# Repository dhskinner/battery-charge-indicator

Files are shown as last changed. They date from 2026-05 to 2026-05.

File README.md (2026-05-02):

# Battery Charge Indicator

Battery Charge Indicator is an ATTiny84-based embedded monitor for lead-acid battery charging systems.

The firmware determines whether charging is active by combining three inputs:

1. Mains AC detection at the charger input (nominal 240V, detected via an isolated/no-contact sensing path).
2. Primary battery DC level above a charging threshold.
3. Secondary battery/house-master channel condition indicating the system state allows charging indication.

When charging is detected, a 12V output runs a repeating PWM fade cycle to drive an external indicator LED. The board also drives onboard status LEDs for quick diagnostics.

## 1) Functionality

### High-level behavior

At runtime, the firmware continuously evaluates three channels:

- **Mains channel** (`channelMains`): checks for a stable AC waveform around 50Hz.
- **Primary channel** (`channelPrimary`): checks DC voltage against a charging threshold.
- **Secondary channel** (`channelSecondary`): checks DC state used as an interlock/condition.

Charging is considered present only when all are true:

- mains AC present,
- primary battery voltage present (above threshold),
- secondary channel **not** present.

This logic is implemented in `IsCharging()` in `src/main.cpp` with a debounce window to avoid false transitions.

### Debounce and signal conditioning

- **Charge-state debounce:** `DEBOUNCE_HYSTERISIS_MS` (default `1000 ms`) requires stable readings before state changes.
- **AC detection debounce:** mains detection validates repeated leading edges in a 50Hz timing window:
	- min interval `15 ms`
	- max interval `25 ms`
	- continuous detection timeout/hysteresis `200 ms`

### PWM output behavior

When charging starts:

- output fade cycle starts (`Fader::StartFade()`),
- brightness ramps up and down using `analogWrite()`,
- step and timing are controlled by:
	- `OUTPUT_PWM_FADE_STEP` (default `4`)
	- `OUTPUT_PWM_FADE_MILLIS` (default `10 ms`)
	- `OUTPUT_PWM_CYCLE_MILLIS` (default `3000 ms` between cycles)

When charging stops:

- fade is stopped gracefully (`Fader::StopFade()`),
- output returns to off state at the end of the current fade cycle.

### Default ATTiny84A channel configuration

Defined in `src/config.h`:

- **Primary sense pin:** `D2`, threshold `13.0V`, scale `21.01V`
- **Secondary sense pin:** `D3`, threshold `10.0V`, scale `21.01V`
- **Mains sense pin:** `D0`, digital threshold `LOW`
- **PWM output pin:** `D8`
- **Onboard LEDs:** primary `D9`, secondary `D10`, mains `D7`

### Startup behavior

On boot (normal mode), the firmware:

1. initializes sensing channels and output,
2. flashes each onboard channel/output LED (`START_FLASHES`, `START_FLASH_MS`),
3. waits `START_DELAY_MS` before entering main loop.

### Optional operating modes

Compile-time options in `src/config.h`:

- `ENABLE_WATCHDOG_TIMER`: enable the watchdog timer for automatic recovery from lockups.
- `ENABLE_WATCHDOG_LOCKUP_TEST`: run a test that watchdog works (not for production code) 
- `ENABLE_CALIBRATION_MODE`: samples ADC channels and blinks out measured values for field calibration.
- `ENABLE_PIN_TEST_MODE`: basic pin/LED test routine (`src/pintest.h`) for validating board mapping and outputs.

## 2) Source Code and Build (PlatformIO)

### Repository layout

- `src/main.cpp`: application setup/loop and charging-state logic.
- `src/channel.h/.cpp`: generic channel abstraction, DC thresholding, AC edge timing.
- `src/fader.h/.cpp`: PWM fade output state machine.
- `src/config.h`: target, pins, thresholds, timing constants, feature flags.
- `src/pintest.h`: pin test helper mode.
- `platformio.ini`: build environment (`attiny84`), upload protocol (`usbasp`), CPU clock, variant.

### Toolchain

- [PlatformIO](https://platformio.org/) with VS Code, or PlatformIO Core CLI.
- AVR target from `platformio.ini`:
	- platform: `atmelavr`
	- board: `attiny84`
	- framework: `arduino`
	- upload protocol: `usbasp`
	- MCU: `attiny84`
	- frequency: `8000000L`
	- variant: `tinyX4_reverse`

### Build and upload using VS Code

1. Open this folder in VS Code.
2. Ensure PlatformIO extension is installed.
3. Open the PlatformIO panel.
4. Under **Project Tasks -> attiny84**:
	 - run **Build** to compile,
	 - run **Upload** to flash via USBasp.

### Build and upload using CLI

From the project root:

```bash
pio run
pio run -t upload
```

### Setting bootloader/fuse for fresh ATTiny84A devices

To burn the bootloader to a fresh Attiny:

1) connect the ICSP header from USBAsp to the target board

```
      ATTiny84A Expander Daughter Board (purple)
      -----------------------------------------
                  -----
      pin 1 MISO |*    | pin 2 5V+
      pin 3 SCK  |     | pin 4 MOSI
      pin 5 RST  |     | pin 6 GND
                  -----
```

2) Setup USBAsp board - refer to here for a guide to USBAsp https://www.freetronics.com.au/pages/usbasp-icsp-programmer-quickstart-guide:
- jumper the "slow clock" header
- select "5V" on the target voltage selection switch
- jumper the 'target power' header

3) Setup some sensible options:
- Board:              Attiny 24/44/84a (no bootloader)
- B.O.D. Level:       Enabled 4.3V (brownout detection) (!! IMPORTANT !!)
- Chip:               Attiny84(a)
- Clock Source:       8MHz (internal)
- Save EEPROM:        EEPROM not retained
- LTO:                Enabled
- millis()/micros():  Enabled
- tinyNeoPixel:       Port A
- Pin mapping:        Clockwise (!! IMPORTANT !!)
- Programmer:         USBAsp (ATTiny Core)

4) Burn bootloader and check all is ok i.e. 2 bytes written

5) On the USBAsp board, remove the "Slow Clock" jumper

6) For a simple proof-of-life test either:
- run a 'Blink' sketch using pin 7,8,9 or 10 (see "pintest.h" for LED pinouts)
- uncomment #define PIN_TEST_MODE below to see all four LED's blinking at the same time
- upload and run this sample:

```code
          int led_pin[4] = {7, 8, 9, 10}, led_index = 0;
          void setup() {
            for (; led_index < 4; led_index++) {
              pinMode(led_pin[led_index], OUTPUT);
              digitalWrite(led_pin[led_index], LOW);
          }}
          void loop() {
            led_index = led_index >= 3 ? 0 : led_index + 1;
            digitalWrite(led_pin[led_index], HIGH); delay(100);
            digitalWrite(led_pin[led_index], LOW); delay(100);
          }
```

7) Upload the production program code as normal using PlatformIO and USBAsp connected via ICSP:
- go to the PlatformIO tab in VSCode and 'Open" this project
- when config is complete, go to the PIO menu bar to the left of the VSCode working area
- the menu for "Project Tasks" should be visible - hit "Upload"

### Fuse bits

`platformio.ini` sets expected signature/fuse values.

Alternatively, the tool AVRDUDESS at (https://github.com/ZakKemble/AVRDUDESS)[https://github.com/ZakKemble/AVRDUDESS] is an easy way to check and set fuse bits.

To read fuse settings run the provided script in Powershell:

```bash
.\tools\read-attiny84a-fuses.ps1 -AvrDude "C:\Program Files (x86)\AVRDUDESS\avrdude.exe" 
```

Or alternatively run: 

```bash
avrdude -c usbasp -p t84 -U efuse:r:-:h -U hfuse:r:-:h -U lfuse:r:-:h
```

Expected values are:

```bash
ATtiny84A fuse report
--------------------
LFUSE: 0xE2
HFUSE: 0xDC
EFUSE: 0xFF

Low fuse (LFUSE)
  CKDIV8     OFF (bit7=1) - Clock divide-by-8 enabled
  CKOUT      OFF (bit6=1) - System clock output on CLKO enabled
  SUT1       ON  (bit5=1) - Start-up time select bit 1
  SUT0       OFF (bit4=0) - Start-up time select bit 0
  CKSEL3     OFF (bit3=0) - Clock source select bit 3
  CKSEL2     OFF (bit2=0) - Clock source select bit 2
  CKSEL1     ON  (bit1=1) - Clock source select bit 1
  CKSEL0     OFF (bit0=0) - Clock source select bit 0
  SUT[1:0]      0b10
  CKSEL[3:0]    0b0010

High fuse (HFUSE)
  RSTDISBL   OFF (bit7=1) - External RESET pin disabled
  DWEN       OFF (bit6=1) - debugWIRE enabled
  SPIEN      ON  (bit5=0) - ISP serial programming enabled
  WDTON      OFF (bit4=1) - Watchdog always on (hardware forced)
  EESAVE     OFF (bit3=1) - EEPROM preserved through chip erase
  BODLEVEL2  ON  (bit2=1) - Brown-out level select bit 2
  BODLEVEL1  OFF (bit1=0) - Brown-out level select bit 1
  BODLEVEL0  OFF (bit0=0) - Brown-out level select bit 0
  BODLEVEL[2:0] 0b100

Extended fuse (EFUSE)
  RES7       ON  (bit7=1) - Reserved (typically left as 1)
  RES6       ON  (bit6=1) - Reserved (typically left as 1)
  RES5       ON  (bit5=1) - Reserved (typically left as 1)
  RES4       ON  (bit4=1) - Reserved (typically left as 1)
  RES3       ON  (bit3=1) - Reserved (typically left as 1)
  RES2       ON  (bit2=1) - Reserved (typically left as 1)
  RES1       ON  (bit1=1) - Reserved (typically left as 1)
  SELFPRGEN  OFF (bit0=1) - Self-programming (SPM) enabled

Note: many AVR fuse features are active-low (bit = 0 means programmed/enabled).
```

Notes: 
1. This firmware is currently configured for `TARGET_PROCESSOR_ATTINY84`
2. Its essential to keep pin mapping/clock settings aligned with your board core configuration when burning fuses. If changing pin mapping, ensure the selected core variant and hardware mapping are consistent before flashing.
3. Many AVR fuse features are active-low (bit = 0 means programmed/enabled).
4. Enabling BOD increases power consumption slightly.
5. Higher BOD thresholds can cause more frequent resets on brief supply dips.
6. If the MCU appears unresponsive after incorrect fuse settings, use HV rescue tooling as referenced in the source comments.

### Calibration

Calibration of the 12V sense lines is performed manually and adjusted in source code. The input voltage range is approximately 0VDC to +20VDC, and ADC response is reasonably linear, as follows:

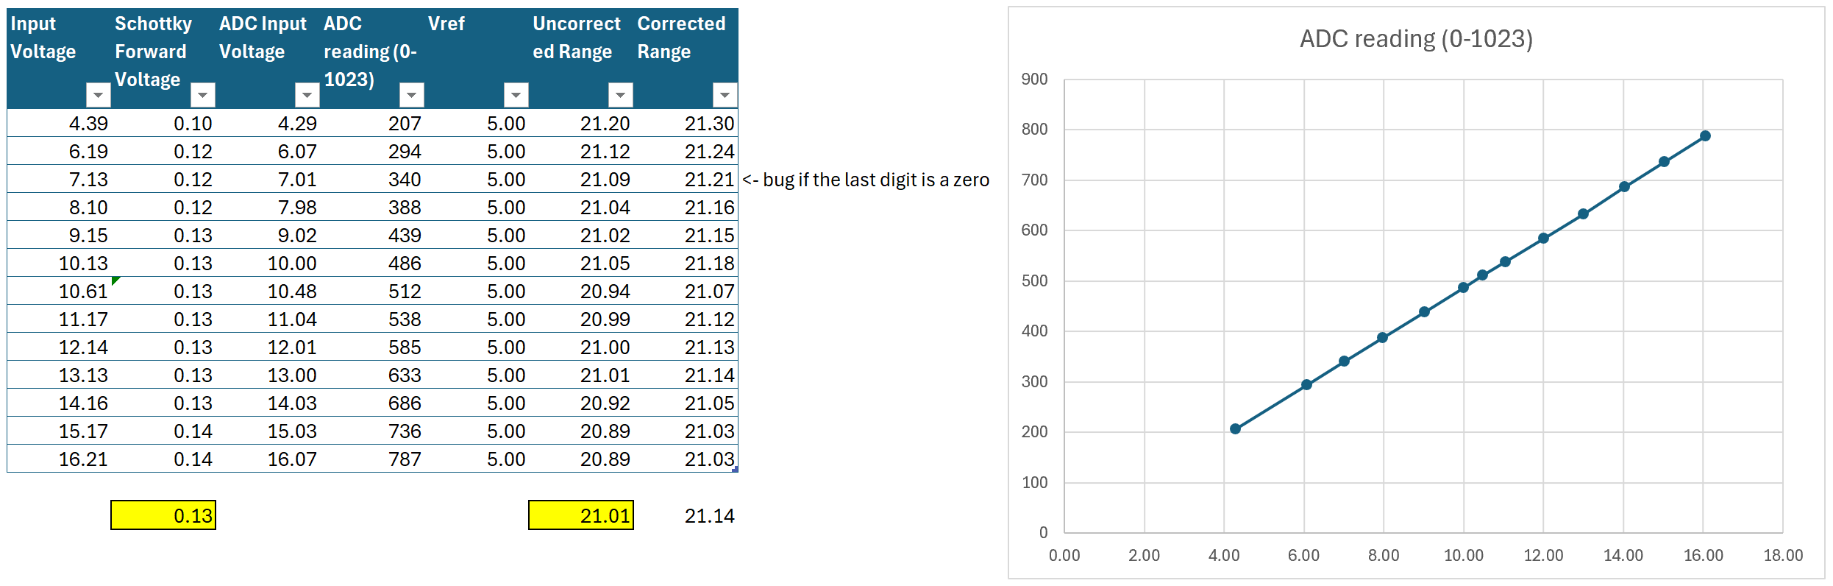
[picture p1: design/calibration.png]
Calibration Reference


- `design/calibration.xlsx`: calibration data workbook.
- `design/calibration.png`: calibration reference graphic.

### Brown-out Detection (BOD)

Brown-out Detection is an ATTiny hardware protection feature that keeps the MCU in reset when supply voltage drops below a configured threshold, to prevents unstable code execution during low-voltage events. This reduces risk of corrupted state, bad ADC readings, and EEPROM write issues.

The MCU restarts cleanly when Vcc returns above the threshold.

### Watchdog Timer

Watchdog support is enabled in firmware (`ENABLE_WATCHDOG_TIMER`) with a configurable timeout (`WATCHDOG_TIMEOUT`, currently 4 seconds).

Implementation summary:

1. At very early startup, firmware captures reset cause (`MCUSR`), clears it, and disables watchdog to prevent reset-loop lockups.
2. After normal setup completes, watchdog is enabled and then fed in the main loop.
3. Long blocking paths (startup LED flash, calibration and pin-test delays) also feed the watchdog to avoid false triggers.
4. If the previous reset was watchdog-caused, a brief LED pattern is shown at boot for diagnostics.

### Troubleshooting

If the Attiny is bricked refer to https://github.com/tsaarni/avr-high-voltage-serial-programming

## 3) Hardware Design

Hardware design assets are in `design/`. 

Electronics were authored using **EasyEDA** in `design/EasyEDA/`. 

Mechanical assets are in `design/Solidworks/`.

This project has three PCB designs:

1. Main Board
2. ATTiny84A Expander Board
3. LED Board

### PCB 1: Main Board

The Main Board is the core controller board containing the ATTiny85, charging logic, sense interfaces, and PWM output stage. 

Originally this was designed for ATTiny85 but was upgraded to ATTiny84A (see the next section)

#### Schematic

Main Board Schematic Page 1

Main Board Schematic Page 2

#### PCB

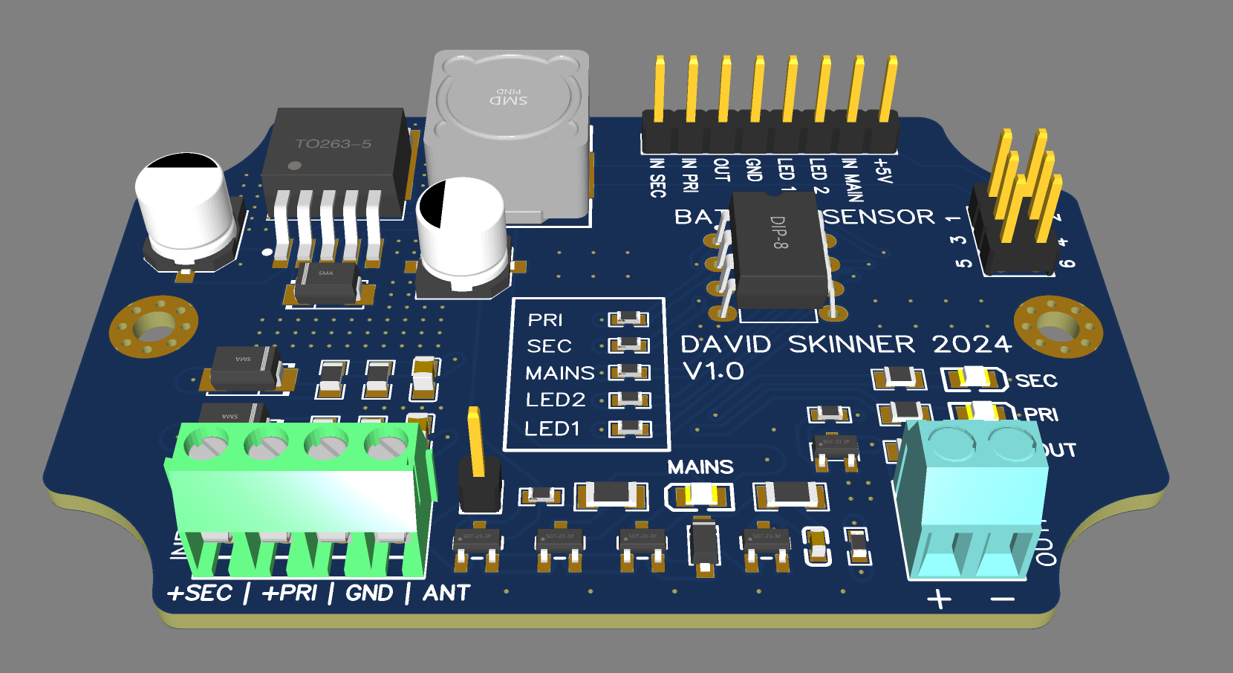
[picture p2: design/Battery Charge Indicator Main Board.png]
Main Board 3D


##### PCB Front (Top)

Main Board Top

##### PCB Back (Bottom)

Main Board Bottom

### PCB 2: ATTiny84A Expander Board

The ATTiny84A Expander Board (daughter board) supports the microcontroller integration/programming workflow and related signal breakout. This was added to replace the original ATTiny85 and provide a little more flexibility.

#### Schematic

ATTiny84A Expander Schematic

#### PCB

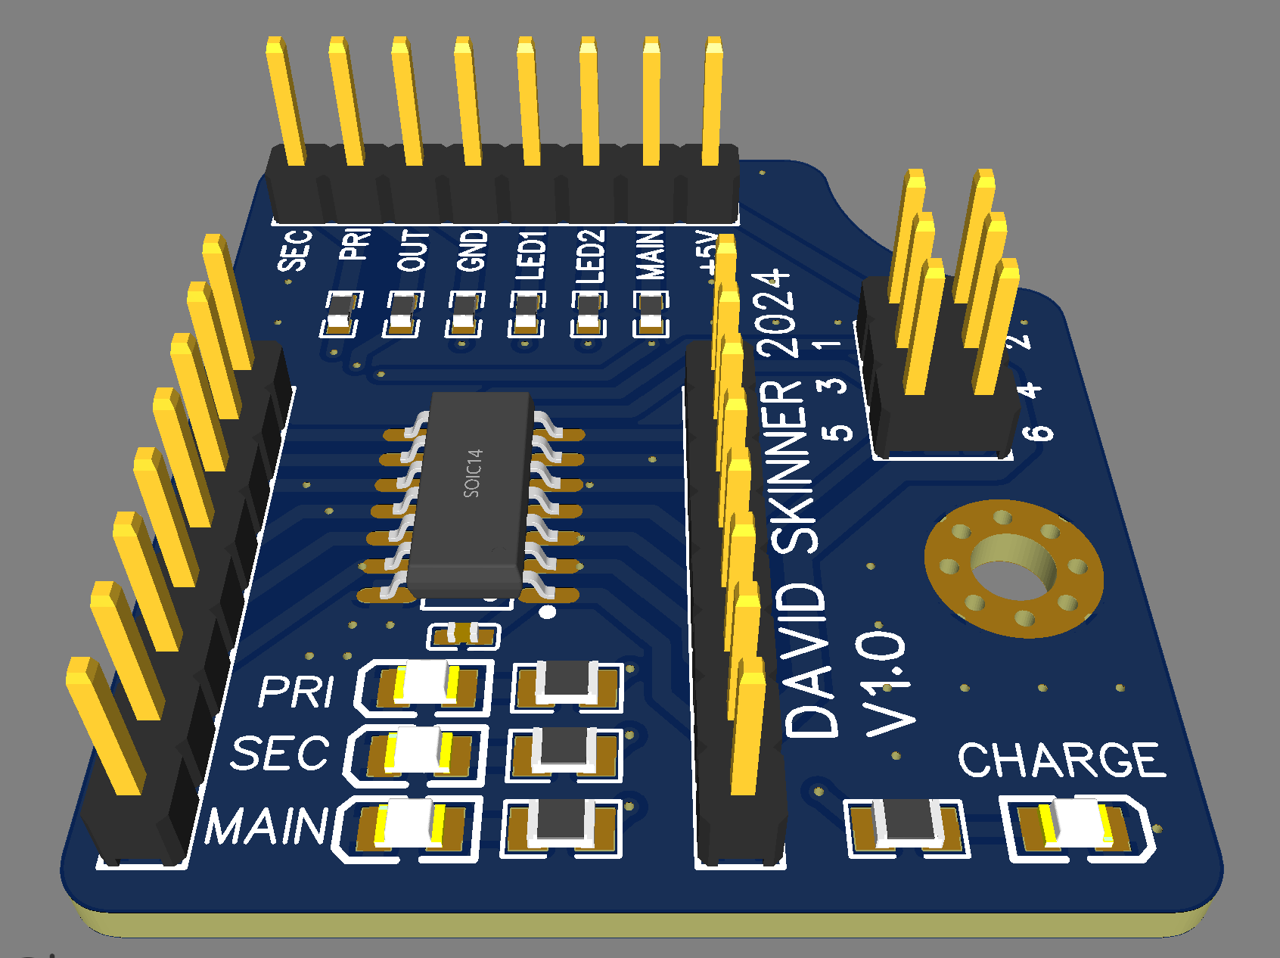
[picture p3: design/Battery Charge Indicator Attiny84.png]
ATTiny84A Expander 3D


##### PCB Front (Top)

ATTiny84A Expander Top

##### PCB Back (Bottom)

ATTiny84A Expander Bottom

### PCB 3: LED Board

The LED Board provides the remote/visible charge indication hardware driven by the PWM output.

#### Schematic

LED Board Schematic

#### PCB

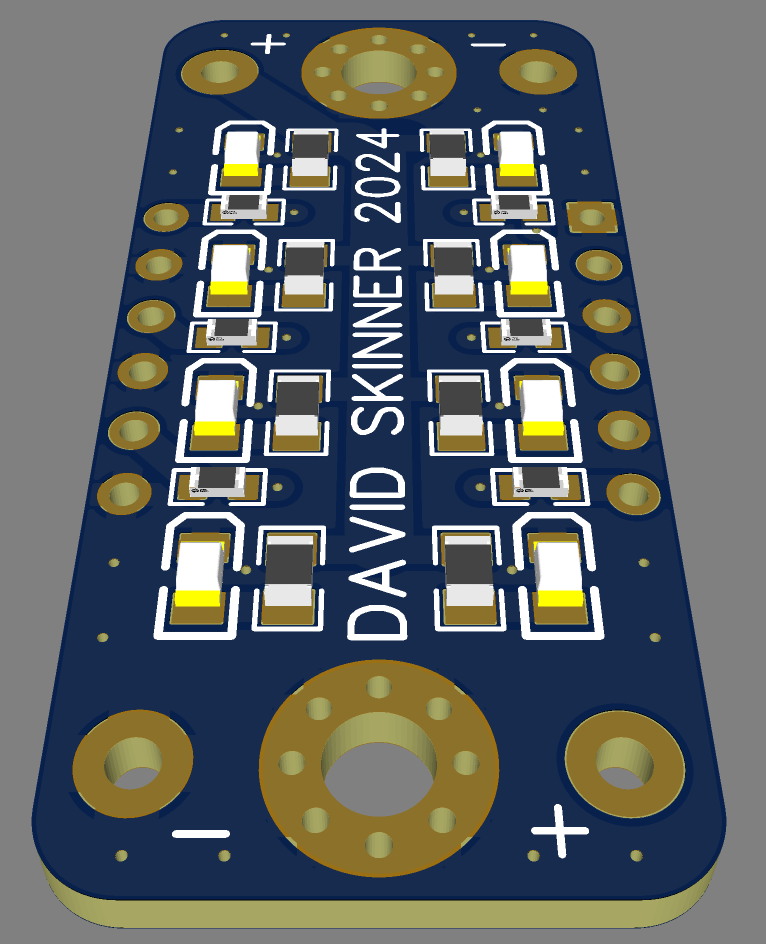
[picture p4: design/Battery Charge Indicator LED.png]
LED Board 3D


##### PCB Front (Top)

LED Board Top

##### PCB Back (Bottom)

LED Board Bottom

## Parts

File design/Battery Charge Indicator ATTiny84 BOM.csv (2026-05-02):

ID | Name | Designator | Footprint | Quantity | Manufacturer Part | Manufacturer | Supplier | Supplier Part | Price
1 | 100nF | C1 | C0402 | 1 | CL05B104KO5NNNC | SAMSUNG(三星) | LCSC | C1525 | 0.001
2 | HDR-M-2.54_1x8 | J1 | HDR-M-2.54_1X8 | 1 |  |  | LCSC | C190820 | 0.043
3 | 1kΩ | R1,R2,R3,R4 | R0805 | 4 | 0805W8F1001T5E | UNI-ROYAL(厚声) | LCSC | C17513 | 0.003
4 | 0Ω | R5,R6,R7,R8,R10,R11 | R0603 | 6 | 0603WAF0000T5E | UNI-ROYAL(厚声) | LCSC | C21189 | 0.002
5 | ATTINY84A-SSF_C1340034 | U4 | SOIC-14_L8.7-W3.9-P1.27-LS6.0-BL | 1 | ATTINY84A-SSF | MICROCHIP(美国微芯) | LCSC | C1340034 | 1.677
6 | 0805G (Green) | CHARGE | LED0805-R-RD | 1 | KT-0805G | KENTO | LCSC | C2297 | 0.016
7 | 17-21SUYC/TR8 | MAIN,PRI,SEC | LED0805-R-RD | 3 | KT-0805黄灯 | KENTO | LCSC | C2296 | 0.012

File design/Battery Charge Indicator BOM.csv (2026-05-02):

ID | Name | Designator | Footprint | Quantity | Manufacturer Part | Manufacturer | Supplier | Supplier Part | Price
1 | SS34_C8678 | D1,D2,D4 | SMA_L4.3-W2.6-LS5.2-RD | 3 | SS34 | MDD(辰达半导体) | LCSC | C8678 | 0.03
2 | 0805G (Green) | CHARGE | LED0805-R-RD | 1 | KT-0805G | KENTO | LCSC | C2297 | 0.016
3 | 17-21SUYC/TR8 | SENSE1,SENSE2 | LED0805-R-RD | 2 | KT-0805黄灯 | KENTO | LCSC | C2296 | 0.012
4 | FC-2012HRK-620D | 240V | LED0805-R-RD | 1 | NCD0805R1 | 国星光电 | LCSC | C84256 | 0.013
5 | 0Ω | MAINS,PRI,SEC,LED1,LED2 | R0603 | 5 | 0603WAF0000T5E | UNI-ROYAL(厚声) | LCSC | C21189 | 0.002
6 | 100nF | C1,C2 | C0805 | 2 | CL21B104KCFNNNE | SAMSUNG(三星) | LCSC | C28233 | 0.01
7 | 330uF | C4,C5 | CAP-SMD_BD6.3-L6.6-W6.6-LS7.6-RD | 2 | HV0J337M0605PZ | HONOR(荣誉) | LCSC | C5246503 | 0.155
8 | 33uH | L1 | IND-SMD_L12.0-W12.0 | 1 | SLH1207S330MTT | Sunltech(韩国顺磁) | LCSC | C181844 | 0.241
9 | AO3400A | Q1 | SOT-23-3_L2.9-W1.3-P1.90-LS2.4-BR | 1 | AO3400A | AOS | LCSC | C20917 | 0.083
10 | 1MΩ | R6 | R0603 | 1 | 0603WAF1004T5E | UNI-ROYAL(厚声) | LCSC | C22935 | 0.002
11 | 1kΩ | R11,R12,R13 | R0805 | 3 | 0805W8F1001T5E | UNI-ROYAL(厚声) | LCSC | C17513 | 0.003
12 | 220Ω | R18 | R0603 | 1 | 0603WAF2200T5E | UNI-ROYAL(厚声) | LCSC | C22962 | 0.002
13 | LM2596S-5.0 | U1 | TO-263-5_L10.2-W8.9-P1.70-BR | 1 | LM2596S-5.0 | UMW(友台半导体) | LCSC | C347421 | 0.592
14 | 10uF | C3 | C0603 | 1 | CL10A106MA8NRNC | SAMSUNG(三星) | LCSC | C96446 | 0.018
15 | 1N4148W_C81598 | D3 | SOD-123F_L2.7-W1.6-LS3.8-RD | 1 | 1N4148W | ST(先科) | LCSC | C81598 | 0.011
16 | 2n3904S-RTK/PS_C18536 | Q2,Q3,Q4,Q5 | SOT-23-3_L2.9-W1.3-P1.90-LS2.4-TR | 4 | 2N3904S-RTK/PS | KEC | LCSC | C18536 | 0.012
17 | 100kΩ | R7 | R1206 | 1 | 1206W4F1003T5E | UNI-ROYAL(厚声) | LCSC | C17900 | 0.005
18 | 10kΩ | R8 | R0603 | 1 | 0603WAF1002T5E | UNI-ROYAL(厚声) | LCSC | C25804 | 0.001
19 | 4.7kΩ | R9 | R1206 | 1 | 1206W4F4701T5E | UNI-ROYAL(厚声) | LCSC | C17936 | 0.005
20 | 150kΩ | R1,R2 | R0805 | 2 | 0805W8F1503T5E | UNI-ROYAL(厚声) | LCSC | C17470 | 0.003
21 | 47kΩ | R3,R4 | R0805 | 2 | 0805W8F4702T5E | UNI-ROYAL(厚声) | LCSC | C17713 | 0.003

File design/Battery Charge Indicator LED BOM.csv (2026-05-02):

ID | Name | Designator | Footprint | Quantity | Manufacturer Part | Manufacturer | Supplier | Supplier Part | Price
1 | DLC/6SGD | D1 | DLC-6SGD | 1 | DLC/6SGD | Kingbright | TME | DLC-6SGB
2 | 0805G (Green) | LED1,LED2,LED3,LED4,LED5,LED6,LED7,LED8 | LED0805-R-RD | 8 | KT-0805G | KENTO | LCSC | C2297 | 0.016
3 | 1kΩ | R1,R2,R3,R4,R5,R6,R7,R8 | R0805 | 8 | 0805W8F1001T5E | UNI-ROYAL(厚声) | LCSC | C17513 | 0.003
4 | 330Ω | R9,R10,R11,R12,R13,R14 | R0603 | 6 | 0603WAF3300T5E | UNI-ROYAL(厚声) | LCSC | C23138 | 0.002
5 | PAD-ROUND-3_2 | U1,U2,U3,U4 | PADPAD | 4

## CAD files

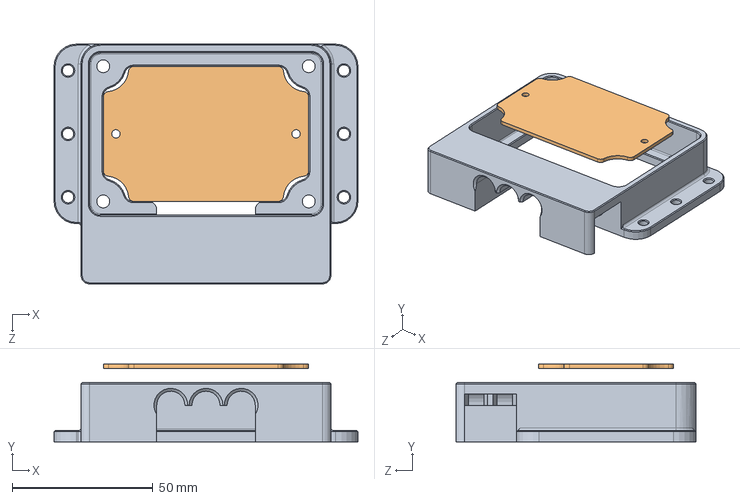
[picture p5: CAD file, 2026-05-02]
design/Solidworks/Mount.SLDASM
108.0 x 27.6 x 85.2 mm
PCB
Collar x 3

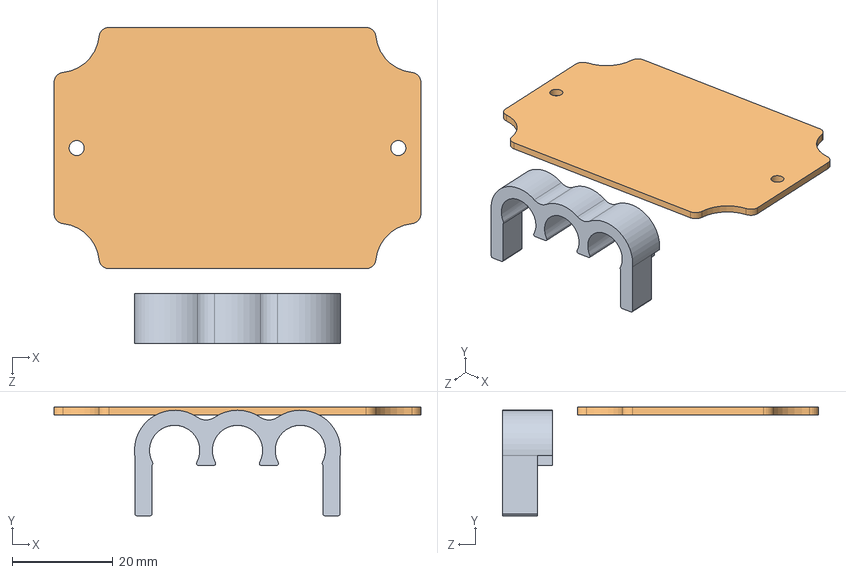
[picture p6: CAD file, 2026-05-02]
design/Solidworks/Mount 2.SLDASM
73.0 x 21.6 x 62.9 mm
PCB
Collar 2 x 3

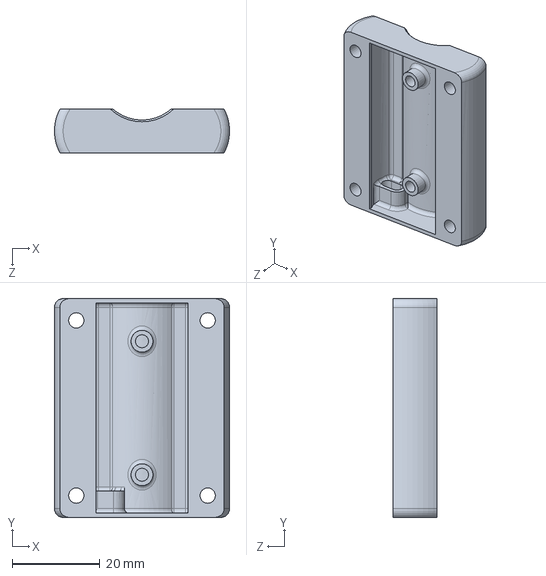
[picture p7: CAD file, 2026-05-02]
design/Solidworks/LED Holder 3.SLDPRT
40.0 x 50.0 x 10.0 mm

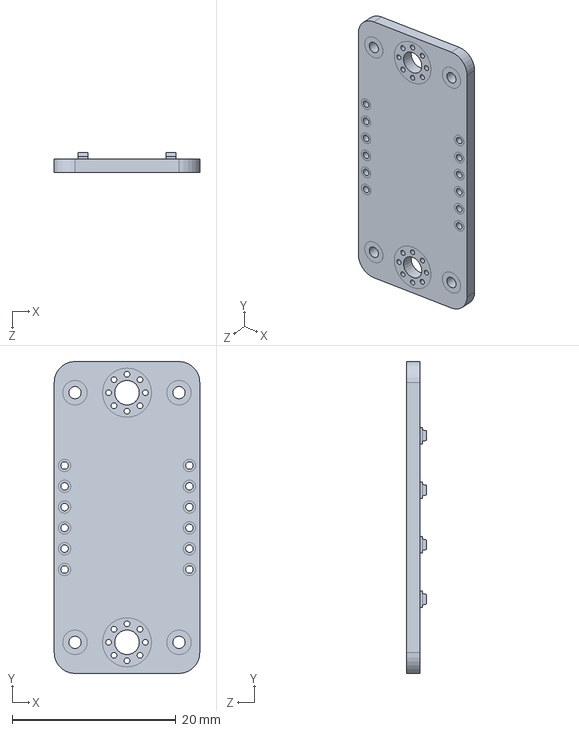
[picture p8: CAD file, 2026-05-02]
design/Solidworks/PCB2.SLDPRT
17.8 x 38.1 x 2.41 mm

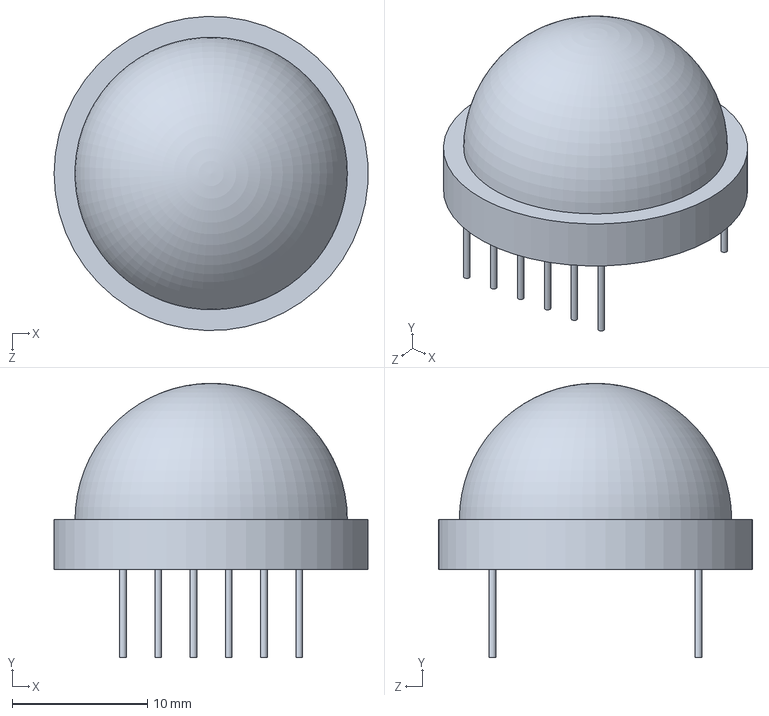
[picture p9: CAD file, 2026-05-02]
design/Solidworks/Big LED.SLDPRT
23.2 x 20.3 x 23.2 mm

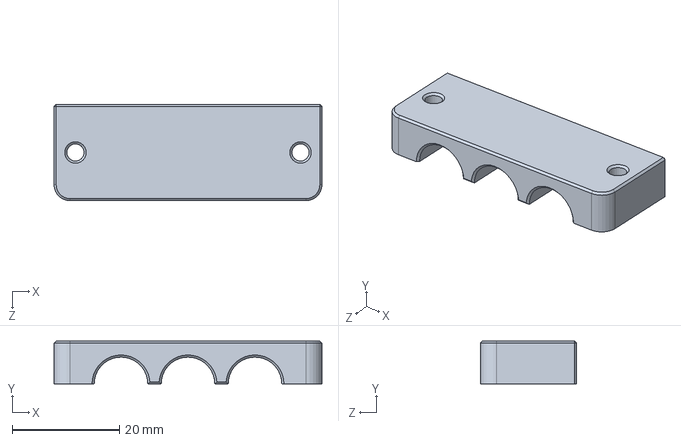
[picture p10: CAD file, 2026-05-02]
design/Solidworks/Collar Keeper.SLDPRT
50.0 x 8.00 x 18.0 mm

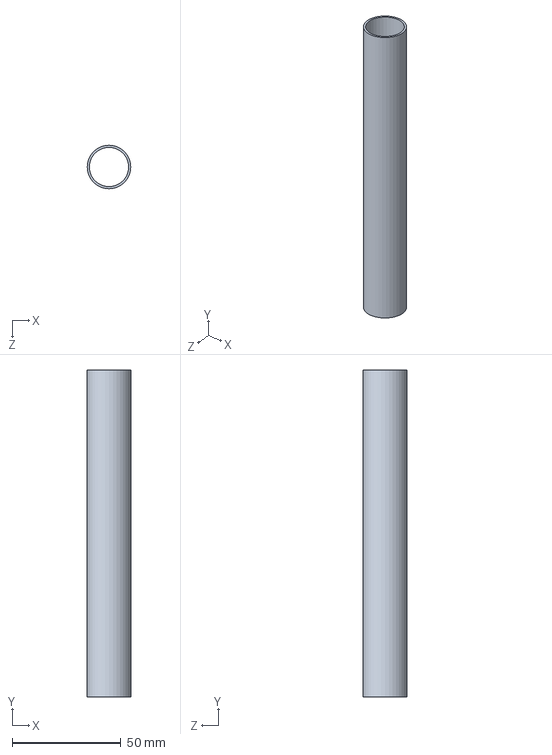
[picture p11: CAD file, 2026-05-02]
design/Solidworks/Stainless tube 20mm.SLDPRT
20.0 x 150.0 x 20.0 mm

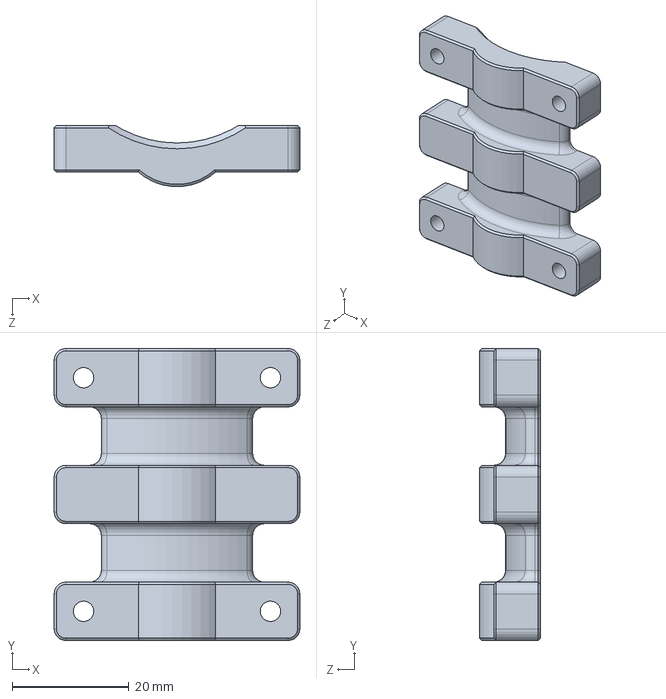
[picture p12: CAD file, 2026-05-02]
design/Solidworks/LED Holder Cable Tie Mount.SLDPRT
42.1 x 50.0 x 10.5 mm

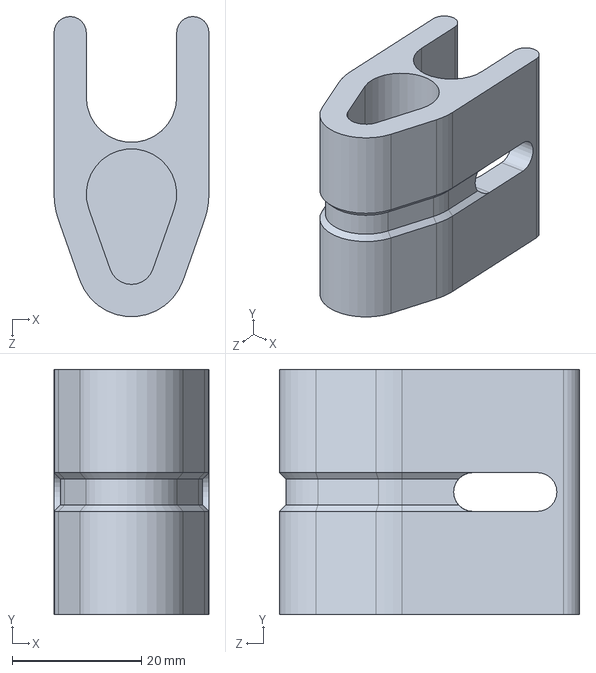
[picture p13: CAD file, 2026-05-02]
design/Solidworks/Antenna Holder.SLDPRT
24.0 x 38.0 x 46.5 mm

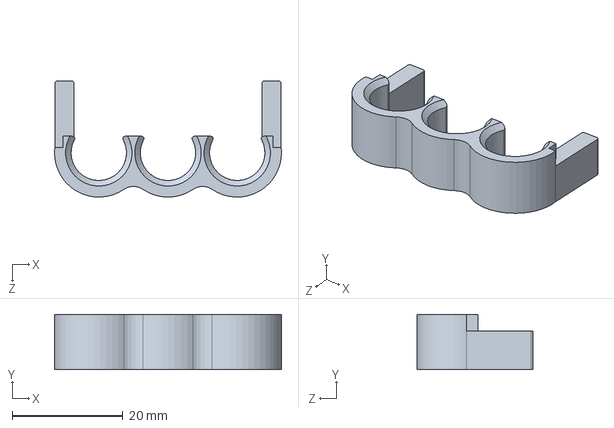
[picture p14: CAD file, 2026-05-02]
design/Solidworks/Collar 2.SLDPRT
41.0 x 10.0 x 21.0 mm

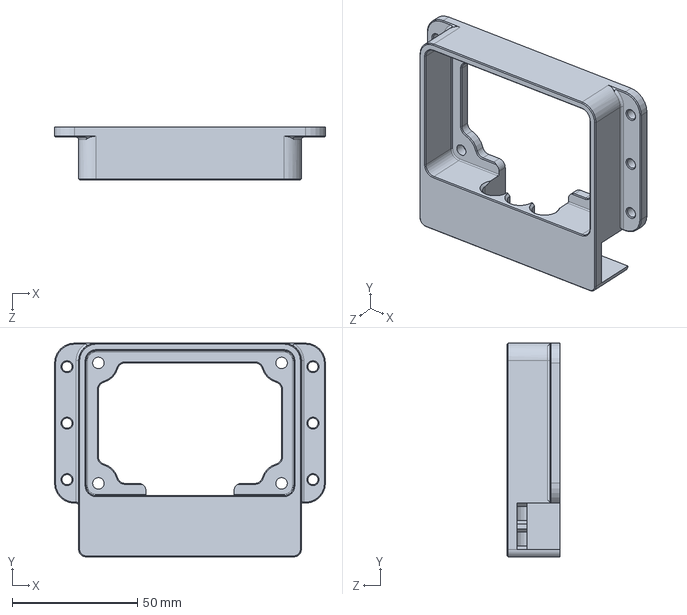
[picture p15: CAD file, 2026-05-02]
design/Solidworks/Collar.SLDPRT
108.0 x 85.2 x 21.0 mm

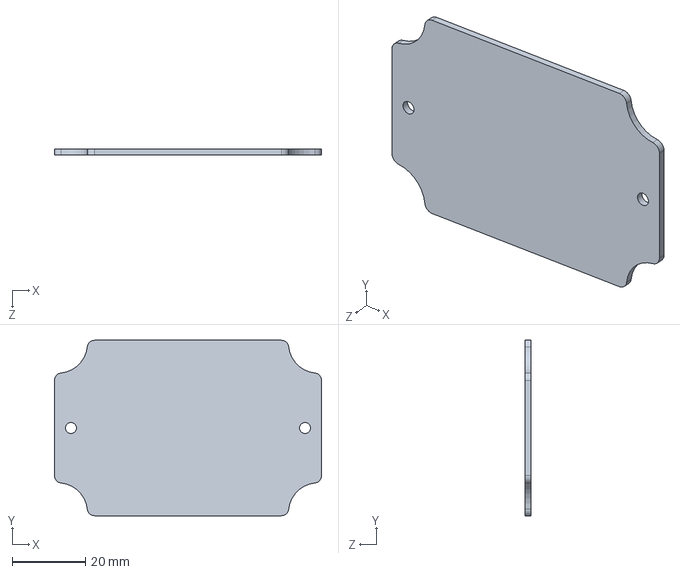
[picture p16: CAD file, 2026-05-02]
design/Solidworks/PCB.SLDPRT
73.0 x 48.0 x 1.60 mm

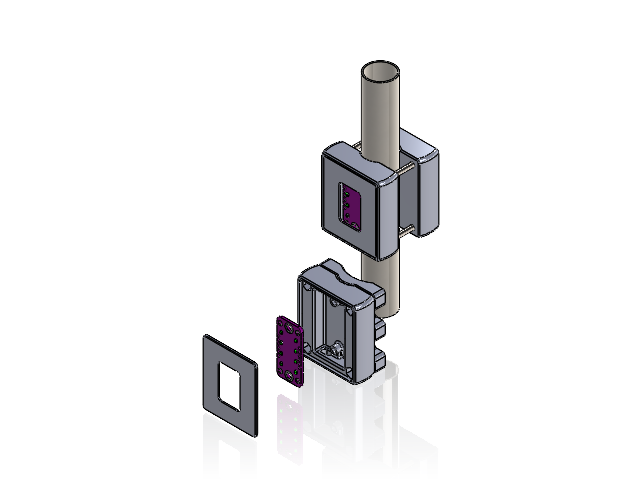
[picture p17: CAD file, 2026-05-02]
design/Solidworks/LED Holder 4.SLDASM
LED Holder 4 x 2
PCB2 x 2
Part2^LED Holder 4
Part3^LED Holder 4 x 2
cross countersunk head screw_as x 4
hexagon nut style 1 (grades a and b) as x 4
Stainless tube 20mm
LED Holder Cable Tie Mount

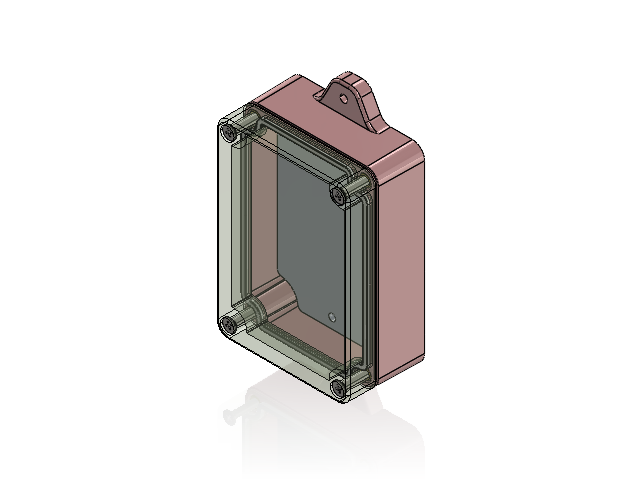
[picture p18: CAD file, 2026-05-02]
design/Solidworks/Enclosure SANHE 11-36.SLDASM
Cover SANHE 11-36-2_1.IGS
SANHE 11-36-1_Body SANHE 11-36-1_1.IGS
Insert_Body SANHE 11-36-1_1.IGS
Screw M4x20C_1.IGS x 4
SANHE MFT2_1.IGS
PCB

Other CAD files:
design/Solidworks/LED Holder.SLDASM
design/Solidworks/LED Holder 2.SLDASM
design/Solidworks/Fuse Holder.SLDPRT
design/Solidworks/Enclosure SANHE 11-36.IGS
design/Solidworks/LED Holder 2.SLDPRT
design/Solidworks/LED Holder 4.SLDPRT
design/Solidworks/LED Holder.SLDPRT
design/Solidworks/Mount.SLDPRT
design/Solidworks/PCB.DXF

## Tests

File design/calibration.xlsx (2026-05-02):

Input Voltage | Schottky Forward Voltage | ADC Input Voltage | ADC reading (0-1023) | Vref | Uncorrected Range | Corrected Range
4.39 | 0.10 | 4.29 | 207 | 5.00 | 21.20 | 21.30
6.19 | 0.12 | 6.07 | 294 | 5.00 | 21.12 | 21.24
7.13 | 0.12 | 7.01 | 340 | 5.00 | 21.09 | 21.21 | <- bug if the last digit is a zero
8.10 | 0.12 | 7.98 | 388 | 5.00 | 21.04 | 21.16
9.15 | 0.13 | 9.02 | 439 | 5.00 | 21.02 | 21.15
10.13 | 0.13 | 10.00 | 486 | 5.00 | 21.05 | 21.18
10.61 | 0.13 | 10.48 | 512 | 5.00 | 20.94 | 21.07
11.17 | 0.13 | 11.04 | 538 | 5.00 | 20.99 | 21.12
12.14 | 0.13 | 12.01 | 585 | 5.00 | 21.00 | 21.13
13.13 | 0.13 | 13.00 | 633 | 5.00 | 21.01 | 21.14
14.16 | 0.13 | 14.03 | 686 | 5.00 | 20.92 | 21.05
15.17 | 0.14 | 15.03 | 736 | 5.00 | 20.89 | 21.03
16.21 | 0.14 | 16.07 | 787 | 5.00 | 20.89 | 21.03
 | 0.13 |  |  |  | 21.01 | 21.14

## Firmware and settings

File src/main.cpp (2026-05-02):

/********************************************************************************
 *  This is a battery charge monitor for lead acid batteries that:
 *   - detects if 240V is available at the input side of the charger and
 *   - measures battery voltage across 2 channels
 *
 *  Written by:  Dave Skinner
 *  Date:        16 December 2024
 *
 ********************************************************************************/

#include "channel.h"
#include "fader.h"
#include "pintest.h"
#include "watchdog.h"

Channel channelPrimary(CHANNEL_PRI_SENSE_PIN, CHANNEL_PRI_THRESHOLD, CHANNEL_PRI_SCALE, CHANNEL_PRI_LED_PIN);
Channel channelSecondary(CHANNEL_SEC_SENSE_PIN, CHANNEL_SEC_THRESHOLD, CHANNEL_SEC_SCALE, CHANNEL_SEC_LED_PIN);
Channel channelMains(CHANNEL_MAINS_SENSE_PIN, CHANNEL_MAINS_THRESHOLD, CHANNEL_MAINS_SCALE, CHANNEL_MAINS_LED_PIN);
Fader channelOutput(OUTPUT_PWM_FADE_PIN);
bool charging = false;
bool IsCharging();

// --------------------------------------------------------------------------------

// run once
void setup()
{
#ifdef ENABLE_PIN_TEST_MODE
  pinTestSetup();
#else
  // setup sense channels
  channelPrimary.Setup();
  channelSecondary.Setup();
  channelMains.Setup();

  // setup the output channel
  channelOutput.Setup();

  // test the onboard leds
  channelPrimary.Flash(START_FLASH_MS, START_FLASHES);
  channelSecondary.Flash(START_FLASH_MS, START_FLASHES);
  channelMains.Flash(START_FLASH_MS, START_FLASHES);
  channelOutput.Flash(START_FLASH_MS, START_FLASHES);
  delay(START_DELAY_MS);
#endif

#ifdef ENABLE_WATCHDOG_TIMER
  indicateWatchdogReset();
  watchdogInit();

#ifdef ENABLE_WATCHDOG_LOCKUP_TEST
  // Force a one-shot lockup test: on non-watchdog boot, turn on green output LED and hang.
  // After watchdog reset, this block is skipped so normal startup can continue.
  if (!watchdogWasReset())
  {
    pinMode(OUTPUT_PWM_FADE_PIN, OUTPUT);
    digitalWrite(OUTPUT_PWM_FADE_PIN, HIGH);
    while (true)
    {
      // intentional lockup to validate watchdog reset behavior
    }
  }
#endif

#endif
}

// run repeatedly
void loop()
{
#ifdef ENABLE_WATCHDOG_TIMER
  watchdogFeed();
#endif

#if defined(ENABLE_CALIBRATION_MODE)

  // calibration mode takes readings from each ADC and blinks out the values
  channelMains.IsAcPresent();
  channelPrimary.Calibrate();
  channelSecondary.Calibrate();

#elif defined(ENABLE_PIN_TEST_MODE)

  // pin test mode is to check basic operation of the LED's and outputs
  pinTestRun();

#else

  // normal operation checks for charging present
  if (!charging && IsCharging())
  {

    // charging is detected so start pwm fade cycle
    channelOutput.StartFade();
  }
  else if (charging && !IsCharging())
  {

    // charging has dropped so stop the pwm fade cycle
    channelOutput.StopFade();
  }

  // run the PWM fade cycle
  channelOutput.RunFade();

#endif
}

// --------------------------------------------------------------------------------

// the logic for charging to be considered present is there must be:
// - 240V detected (mains channel)
// - charge voltage on the battery terminals (primary channel)
// - house master is off (secondary channel)
bool IsCharging()
{
  static bool lastDebounceState = false;
  static unsigned long lastDebounceTime = 0;

  // read the current charging state - remember you can't do this
  // all in one statement because of lazy evaluation (ffs)
  bool reading = channelMains.IsAcPresent();
  reading &= channelPrimary.IsDcPresent();
  reading &= !channelSecondary.IsDcPresent();

  // if the state changed, due to noise or actual changes in readings, reset the debounce timer
  if (reading != lastDebounceState)
  {
    lastDebounceState = reading;
    lastDebounceTime = millis();
  }

  // if the state has stable for longer than the debounce delay, take it as current
  if ((millis() - lastDebounceTime) > DEBOUNCE_HYSTERISIS_MS)
    charging = reading;

  return charging;
}

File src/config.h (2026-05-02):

/********************************************************************************
 *  This is a battery charge monitor for lead acid batteries that:
 *   - detects if 240V is available at the input side of the charger and
 *   - measures battery voltage across 2 channels
 *
 *  Written by:  Dave Skinner
 *  Date:        16 December 2024
 *
 ********************************************************************************/

#pragma once
#ifndef _CONFIG_H_
#define _CONFIG_H_

#include "Arduino.h"
#include <avr/wdt.h>

// set the target processor - either TARGET_PROCESSOR_ATTINY85 or TARGET_PROCESSOR_ATTINY84
#define TARGET_PROCESSOR_ATTINY84

// uncomment to enable calibration mode to check the primary and secondary sense channels
// #define ENABLE_CALIBRATION_MODE

// uncomment to enable pin test mode to check we have the right mapping
// #define ENABLE_PIN_TEST_MODE

// uncomment to enable the watchdog timer for automatic recovery from lockups
#define ENABLE_WATCHDOG_TIMER

// watchdog timeout period (see <avr/wdt.h> WDTO_* options)
#define WATCHDOG_TIMEOUT WDTO_4S

// temporary watchdog validation mode:
// when enabled, firmware turns on the green output LED (OUTPUT_PWM_FADE_PIN) then intentionally hangs once
// so watchdog can reset the MCU; this test auto-skips after a watchdog reset
// #define ENABLE_WATCHDOG_LOCKUP_TEST

// watchdog reset indication pattern on startup (all three onboard channel LEDs)
#define WATCHDOG_RESET_FLASHES 10
#define WATCHDOG_RESET_FLASH_MS 75

#define START_FLASHES 1              // number of times to flash each LED on startup
#define START_FLASH_MS 200           // duration to flash LEDs on startup
#define START_DELAY_MS 1000          // delay on startup
#define DEBOUNCE_HYSTERISIS_MS 1000  // milliseconds to debounce state changes
#define MAINS_50Hz_MINIMUM_MILLIS 15 // lower threshold for detecting 50Hz (15ms = 67Hz)
#define MAINS_50Hz_MAXIMUM_MILLIS 25 // upper threshold for detecting 50Hz (20ms = 40Hz)
#define MAINS_50HZ_HYSTERISIS_MS 200 // time to wait for continuous 50Hz (200msec is about 10 zero crossings at consistent 50Hz)
#define SCHOTTKY_FORWARD_VOLTS 0.13f // forward voltage drop of the schottky diode inline in pri and sec channel sense

#ifdef TARGET_PROCESSOR_ATTINY84
/*
ATMEL ATTINY84A - CLOCKWISE PINS  !!!! IMPORTANT THIS IS SET CORRECTLY IN THE BOOTLOADER !!!
                                             +-\/-+
                                       VCC  1|    |14  GND
            LED 2 |            (D 10)  PB0  2|    |13  PA0  (D  0)        AREF | Sense Main
            LED 1 |            (D  9)  PB1  3|    |12  PA1  (D  1)             | Serial Tx
            RESET |            (D 11)  PB3  4|    |11  PA2  (D  2)             | Sense Primary
           Output | PWM  INT0  (D  8)  PB2  5|    |10  PA3  (D  3)             | Sense Secondary
         LED Main | PWM        (D  7)  PA7  6|    |9   PA4  (D  4)             | SCK
             MOSI | PWM        (D  6)  PA6  7|    |8   PA5  (D  5)        PWM  | MISO
                                             +----+
*/
#define CHANNEL_PRI_LED_PIN 9        // onboard yellow LED
#define CHANNEL_PRI_SENSE_PIN 2      // pin for 12V ADC channel
#define CHANNEL_PRI_THRESHOLD 13.0f  // threshold above which battery is charging e.g. ~14.0V - lead acid should be around 12.8V at rest
#define CHANNEL_PRI_SCALE 21.01f     // dynamic range of the primary sense channel - tested range for first board is 0v to 21.0V
#define CHANNEL_SEC_LED_PIN 10       // onboard yellow LED
#define CHANNEL_SEC_SENSE_PIN 3      // pin for 12V ADC channel
#define CHANNEL_SEC_THRESHOLD 10.0f  // threshold above which battery is present e.g. ~10.0V
#define CHANNEL_SEC_SCALE 21.01f     // dynamic range of the sense channel e.g. 0v to 21.0V
#define CHANNEL_MAINS_LED_PIN 7      // onboard yellow LED
#define CHANNEL_MAINS_SENSE_PIN 0    // pin for 240V no-contact sensor channel - default PB2
#define CHANNEL_MAINS_THRESHOLD LOW  // threshold to indicate signal is present (HIGH or LOW indicate digital IO)
#define CHANNEL_MAINS_SCALE 1.0f     // dynamic range of the sense channel (not used for AC sensing)
#define OUTPUT_PWM_FADE_PIN 8        // 12V PWM LED output
#define OUTPUT_PWM_FADE_STEP 4       // step for each increment of PWM brightness
#define OUTPUT_PWM_FADE_MILLIS 10    // milliseconds for each step of PWM brightness
#define OUTPUT_PWM_CYCLE_MILLIS 3000 // milliseconds between successive PWM fade cycles
#endif
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

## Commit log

2026-05-02 Initial upload
    [Antenna Holder.SLDPRT, Big LED.SLDPRT, Collar 2.SLDPRT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]
2026-05-02 Clarified brownout detection
    [Battery Charge Indicator ATTiny84 BOM.csv, Battery Charge Indicator BOM.csv, Battery Charge Indicator LED BOM.csv]
